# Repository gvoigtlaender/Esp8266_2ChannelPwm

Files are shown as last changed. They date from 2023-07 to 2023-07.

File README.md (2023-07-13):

# Esp8266_2ChannelPwm
## ESP8266 based 2-Channel LED Controller 
* ESP12F 
* LM2596S step-down converter
* 2 PWM Channels (white & blue light)
* AO3400A N-Channel MOSFET to directly drive LEDs (tested with 24V 1A)
* onboard RST button
* connector for PGM button, to be used as general purpose button as well
* connector for THT LED
* JST programming connector
* power in / out soldering with up to 1.75mm diameter
* designed to fit into Hammond Electronics 1551HFLBK 60 x 35 x 20 ABS Euro-Case

## Schematic
schematic

## PCB
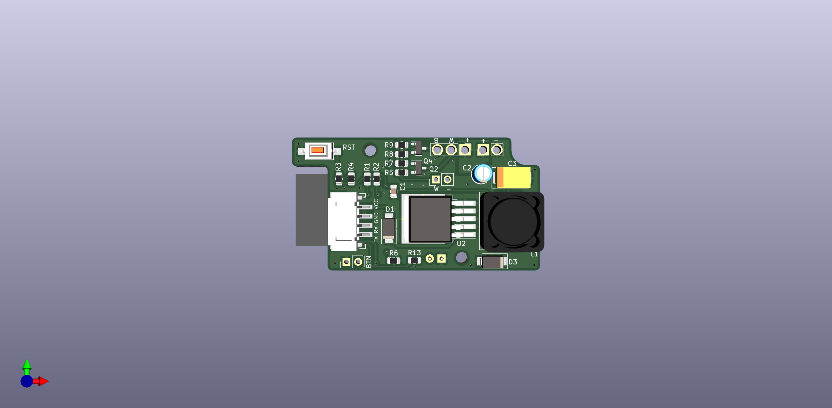
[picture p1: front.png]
front


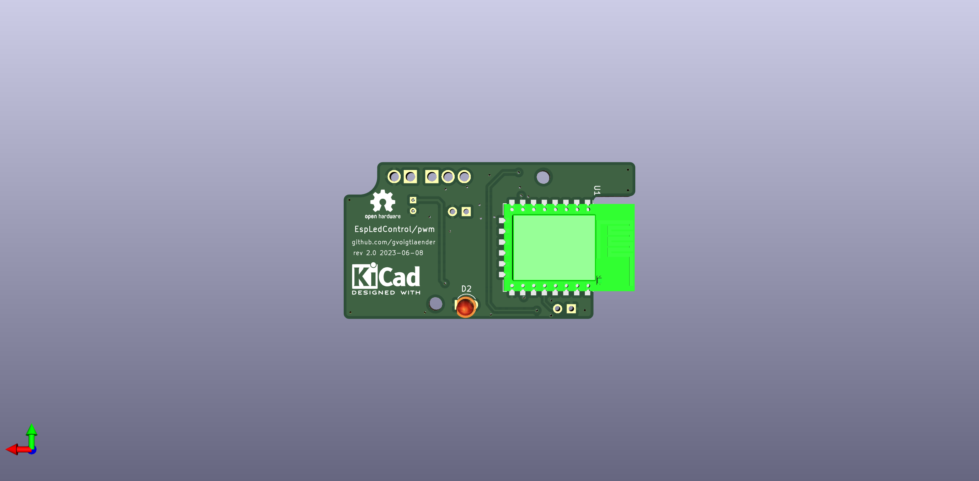
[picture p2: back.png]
back


## Case
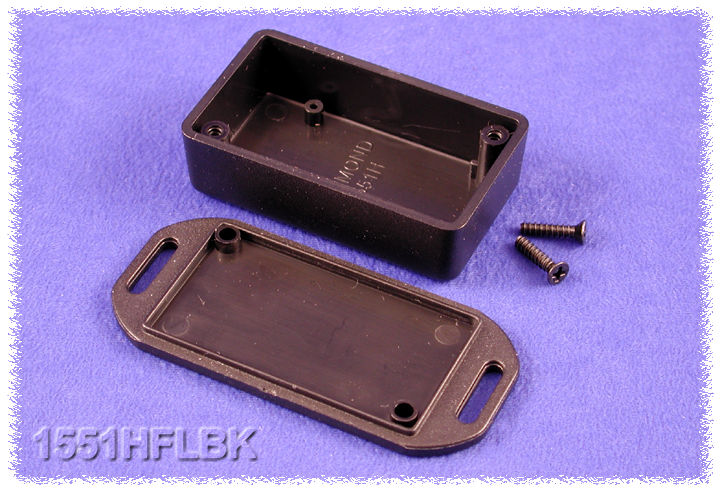
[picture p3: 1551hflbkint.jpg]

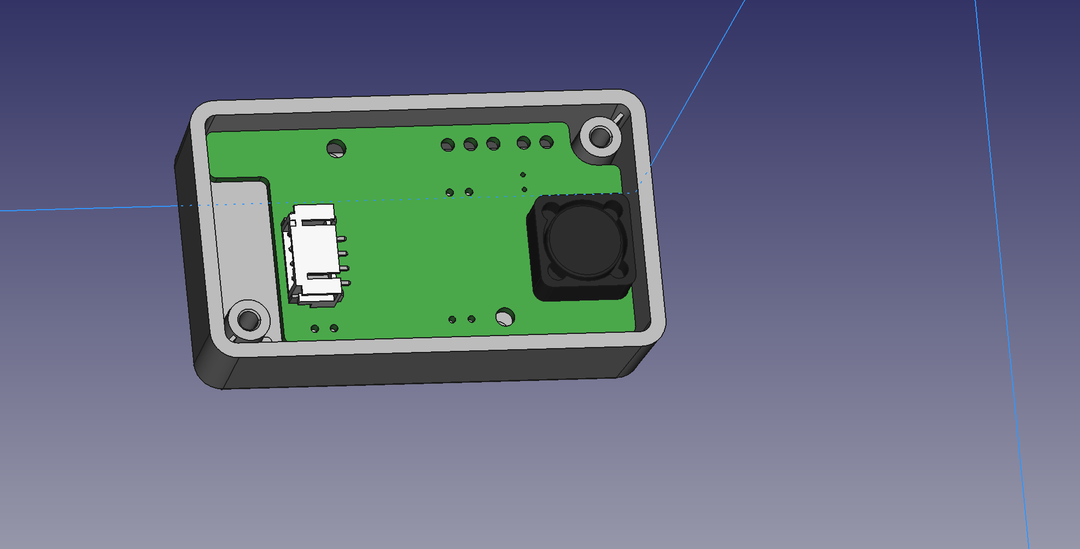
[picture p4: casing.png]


## Complete 
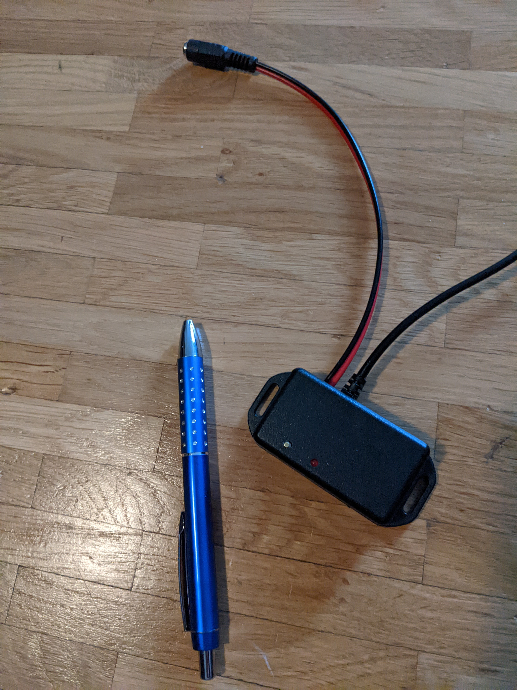
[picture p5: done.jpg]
done


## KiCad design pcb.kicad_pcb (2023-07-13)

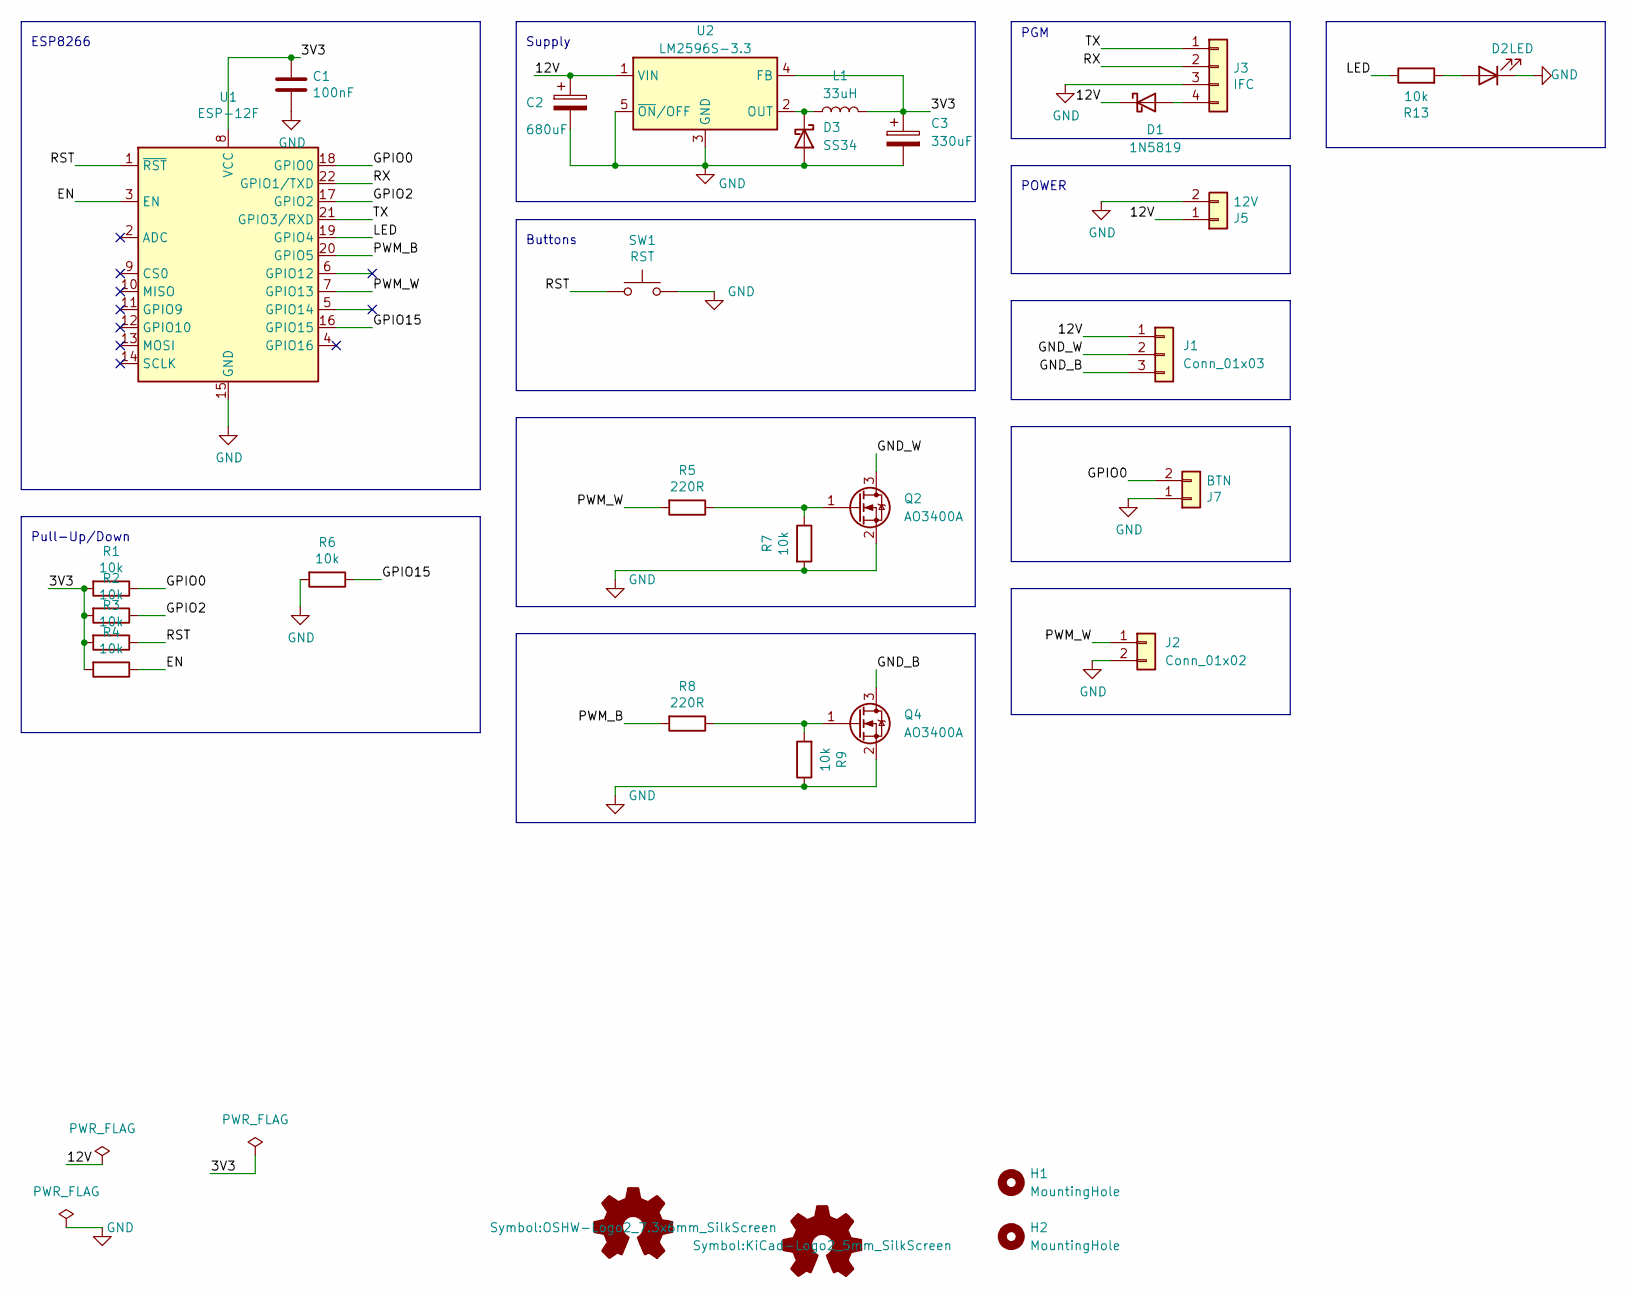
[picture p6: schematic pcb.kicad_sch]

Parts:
C1: 100nF; C_0805_2012Metric; LCSC C49678
C2: 680uF; CP_Radial_D4.0mm_P2.00mm
C3: 330uF; CP_EIA-7343-20_Kemet-V
D1: 1N5819; D_SMA
D2: LED; LED_D3.0mm
D3: SS34; D_SMA
H1, H2: MountingHole; MountingHole_2.5mm
J1: Conn_01x03; PinHeader_1x03_P2.54mm_Vertical
J2: Conn_01x02; PinHeader_1x02_P2.54mm_Vertical
J3: IFC; JSTPH4
J5: 12V; PinHeader_1x02_P2.54mm_Vertical
J7: BTN; PinHeader_1x02_P2.54mm_Vertical
L1: 33uH; L_12x12mm_H6mm
Q2, Q4: AO3400A; SOT-23
R1, R2, R3, R4, R6, R7, R9, R13: 10k; R_0805_2012Metric; LCSC C17414
R5, R8: 220R; R_0805_2012Metric; LCSC C17414
SW1: RST; SW_SPST_CK_RS282G05A3
U1: ESP-12F; ESP-12E
U2: LM2596S-3.3; TO-263-5_TabPin3

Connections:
/3V3: C1.1, C3.1, L1.2, R1.2, R2.2, R3.2, R4.2, U1.8 (VCC), U2.4 (FB)
/12V: C2.1, D1.1 (K), J1.1, J5.1, U2.1 (VIN)
/EN: R4.1, U1.3 (EN)
/GND_B: J1.3, Q4.3 (D)
/GND_W: J1.2, Q2.3 (D)
/GPIO0: J7.2, R1.1, U1.18 (GPIO0)
/GPIO2: R2.1, U1.17 (GPIO2)
/GPIO15: R6.1, U1.16 (GPIO15)
/LED: R13.1, U1.19 (GPIO4)
/PWM_B: R8.2, U1.20 (GPIO5)
/PWM_W: J2.1, R5.2, U1.7 (GPIO13)
/RST: R3.1, SW1.1, U1.1 (~RST)
/RX: J3.2, U1.22 (GPIO1/TXD)
/TX: J3.1, U1.21 (GPIO3/RXD)
GND: C1.2, C2.2, C3.2, D2.1 (K), D3.2 (A), J2.2, J3.3, J5.2, J7.1, Q2.2 (S), Q4.2 (S), R6.2, R7.2, R9.1, SW1.2, U1.15 (GND), U2.3 (GND), U2.5 (~ON/OFF)
unnamed: D1.2 (A), J3.4
unnamed: D2.2 (A), R13.2
unnamed: D3.1 (K), L1.1, U2.2 (OUT)
unnamed: Q2.1 (G), R5.1, R7.1
unnamed: Q4.1 (G), R8.1, R9.2

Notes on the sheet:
ESP8266
Buttons
Supply
POWER
PGM
Pull-Up/Down

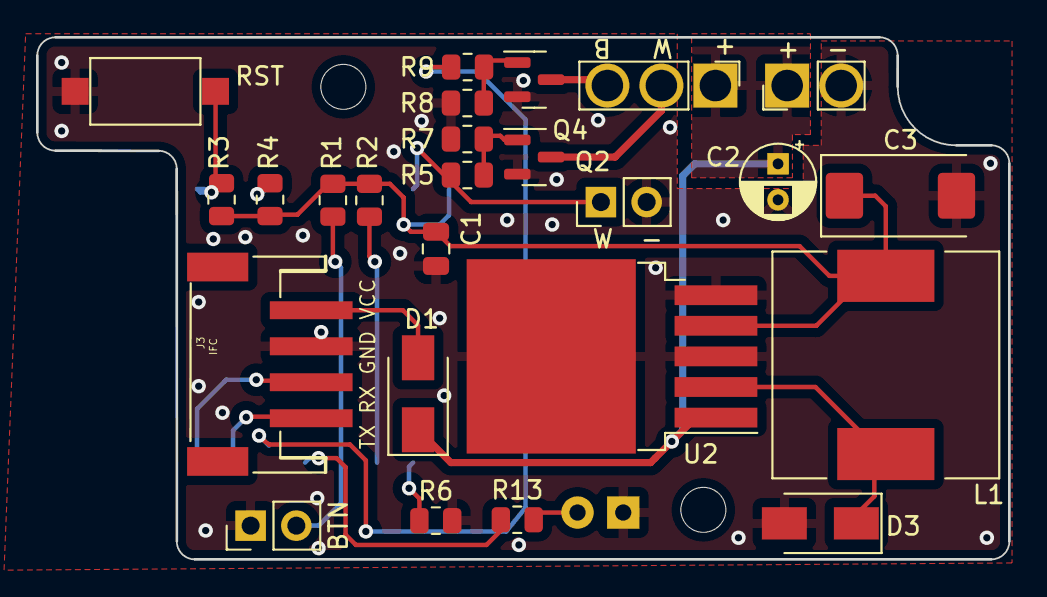
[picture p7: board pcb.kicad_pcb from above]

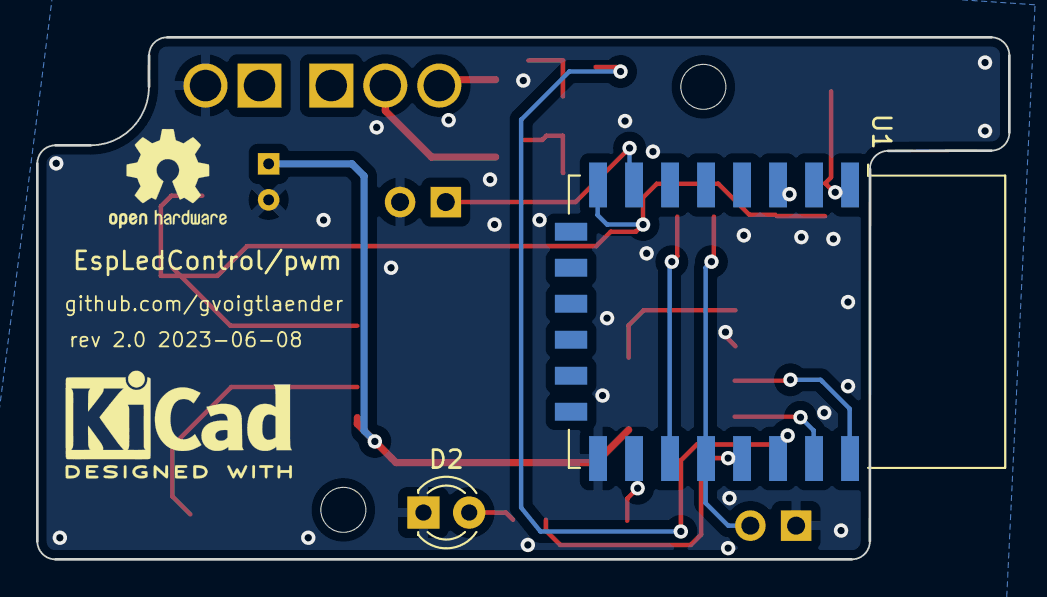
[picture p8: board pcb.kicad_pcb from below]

Board: 2 copper layers, 54.0 x 29.0 mm, 29 parts (2 on the bottom side), 20 nets.
